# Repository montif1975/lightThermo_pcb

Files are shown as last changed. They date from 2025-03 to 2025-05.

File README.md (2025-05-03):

# lightThermo_pcb
PCB carrier board for lightThermo, based on Raspberry PICO.

Schematic, PCB and construction files (gerber) for PBC carrier for lightThermo but can be used to connect generic I2C add-on on Raspberry PICO.

The project contains two folders:
- lightThermo is the schematic and PCB for single device
- lightThermo_panel is the multi-PCB construction file (2 PCB in a single frame)

The project is made with KiCad 9.0.

The resulting PCB is:
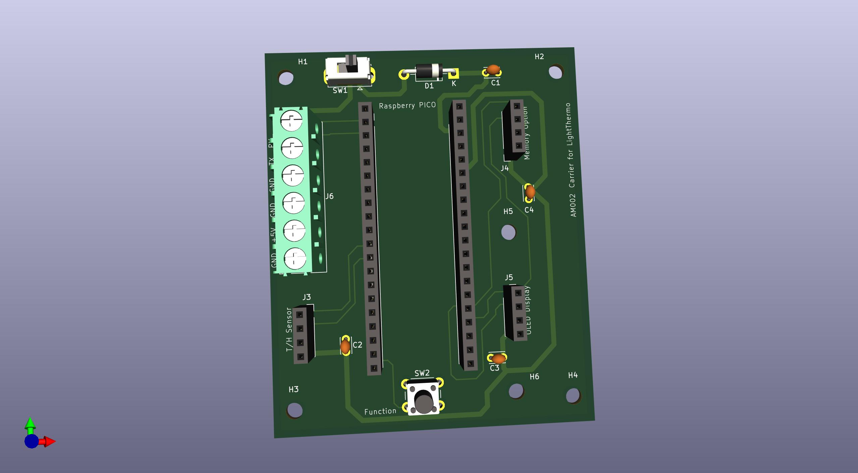
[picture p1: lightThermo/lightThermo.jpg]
lighThermo PCB for carrier board lightThermo


The multi-PCB frame is:
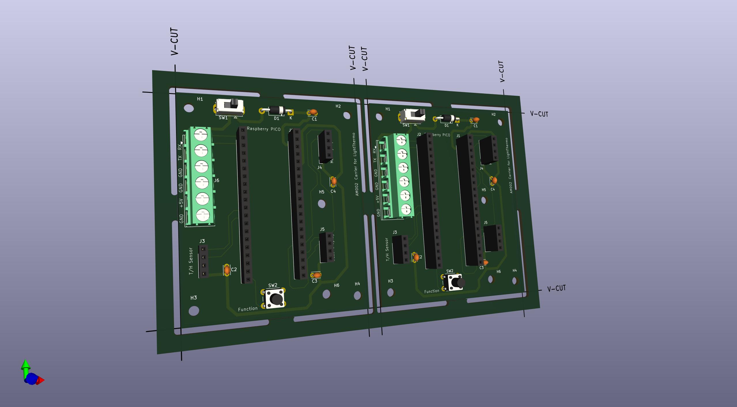
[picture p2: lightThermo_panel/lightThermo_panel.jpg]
lightThermo_panel multi-PCB of carrier board for lightThermo


I printed and assembled some samples, here the PCB (without the PICO and the I2C devices):
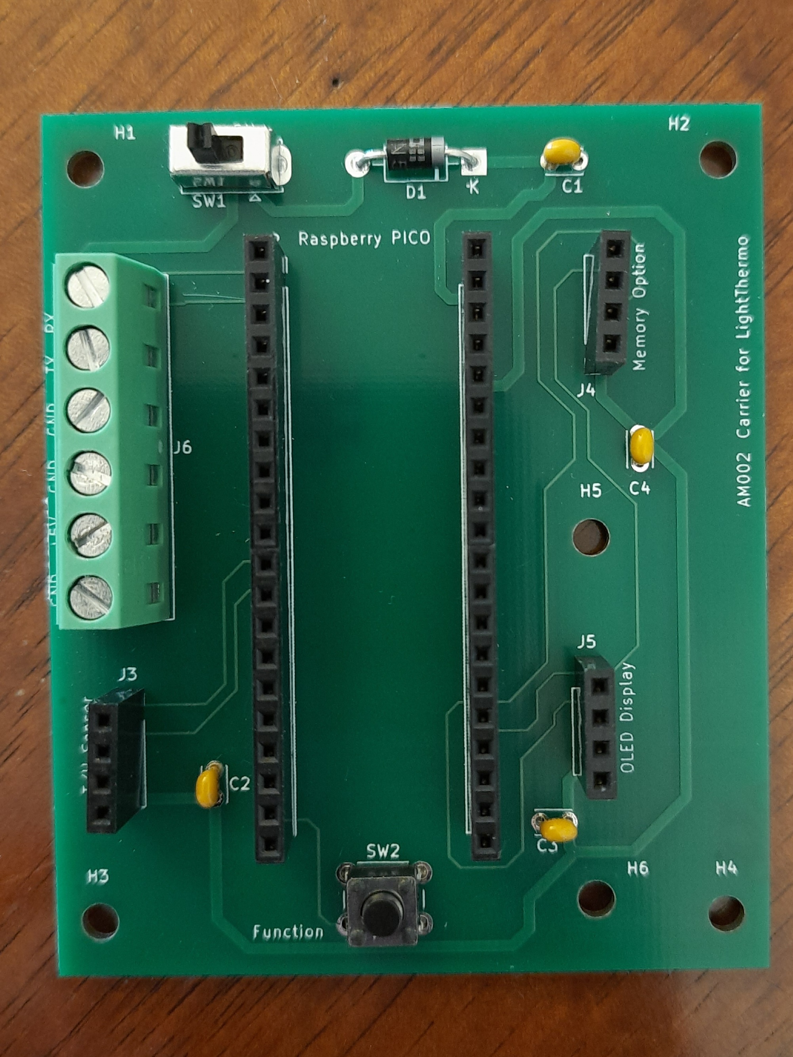
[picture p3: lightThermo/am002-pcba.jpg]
lighThermo PCB for carrier board lightThermo


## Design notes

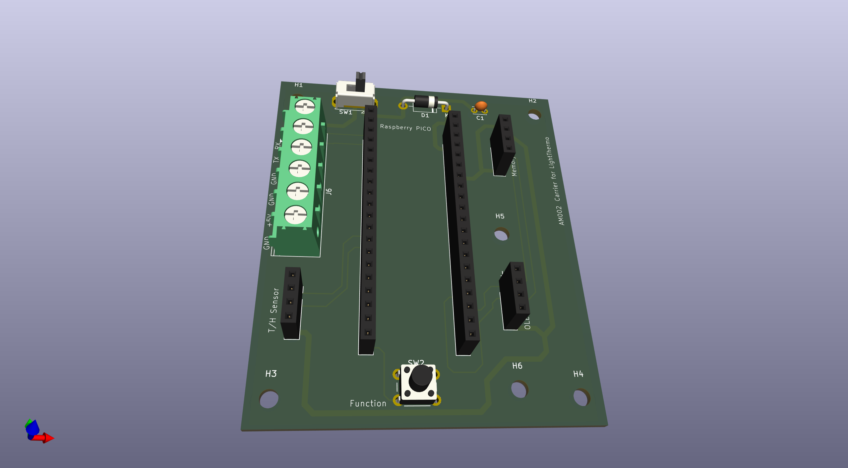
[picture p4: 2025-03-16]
lightThermo/lightThermo.png

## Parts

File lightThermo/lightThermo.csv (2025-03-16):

Reference | Value | Datasheet | Footprint | Qty | DNP
C1,C2,C3,C4 | 100nF | ~ | Capacitor_THT:C_Disc_D3.0mm_W2.0mm_P2.50mm | 4
D1 | 1N5817 | http://www.vishay.com/docs/88525/1n5817.pdf | Diode_THT:D_DO-41_SOD81_P10.16mm_Horizontal | 1
J1 | pico R | ~ | Connector_PinSocket_2.54mm:PinSocket_1x20_P2.54mm_Vertical | 1
J2 | pico L | ~ | Connector_PinSocket_2.54mm:PinSocket_1x20_P2.54mm_Vertical | 1
J3 | Sensor T/H | ~ | Connector_PinSocket_2.54mm:PinSocket_1x04_P2.54mm_Vertical | 1
J4 | Memory Option | ~ | Connector_PinSocket_2.54mm:PinSocket_1x04_P2.54mm_Vertical | 1
J5 | Display OLED | ~ | Connector_PinSocket_2.54mm:PinSocket_1x04_P2.54mm_Vertical | 1
J6 | Screw_Terminal_01x06 | ~ | TerminalBlock_Phoenix:TerminalBlock_Phoenix_PT-1,5-6-5.0-H_1x06_P5.00mm_Horizontal | 1
SW1 | SW_SPST | ~ | Button_Switch_THT:SW_Slide_SPDT_Straight_CK_OS102011MS2Q | 1
SW2 | SW_Push | ~ | Button_Switch_THT:SW_PUSH_6mm_H8mm | 1

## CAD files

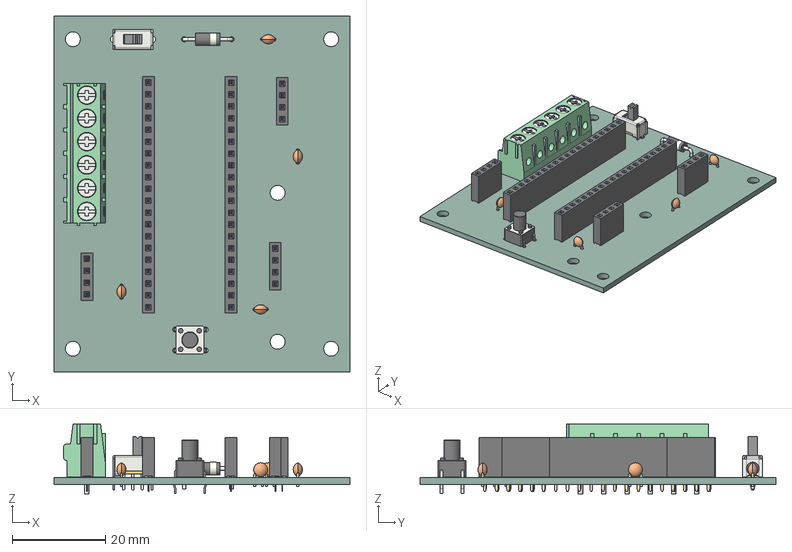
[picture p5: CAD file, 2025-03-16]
lightThermo/lightThermo.step
63.5 x 76.5 x 15.0 mm
C_Disc_D3.0mm_W2.0mm_P2.50mm x 4
D_DO-41_SOD81_P10.16mm_Horizontal
PinSocket_1x04_P2.54mm_Vertical x 3
PinSocket_1x20_P2.54mm_Vertical x 2
SW_Slide_SPDT_Straight_CK_OS102011MS2Q
SW_PUSH_6mm_H8mm
TerminalBlock_Phoenix_PT-1,5-6-5.0-H_1x06_P5.00mm_Horizontal
lightThermo_PCB

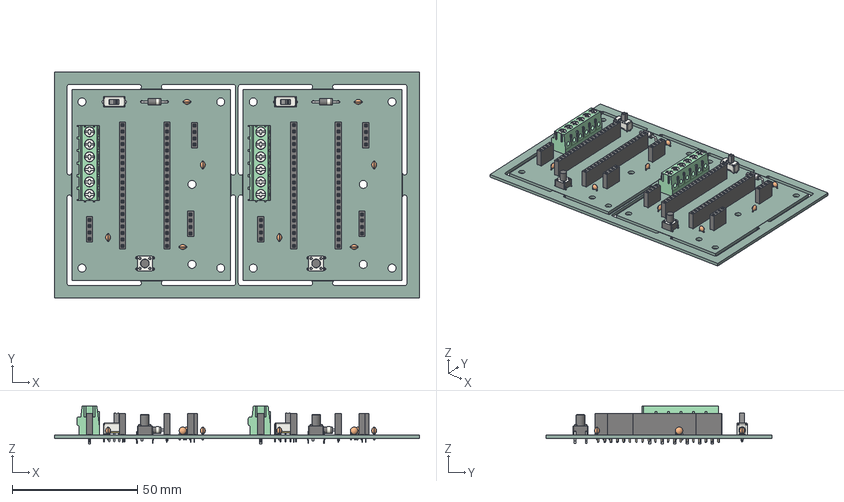
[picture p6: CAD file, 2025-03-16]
lightThermo_panel/lightThermo_panel.step
146.0 x 90.5 x 15.0 mm
PinSocket_1x04_P2.54mm_Vertical x 6
C_Disc_D3.0mm_W2.0mm_P2.50mm x 8
TerminalBlock_Phoenix_PT-1,5-6-5.0-H_1x06_P5.00mm_Horizontal x 2
SW_PUSH_6mm_H8mm x 2
PinSocket_1x20_P2.54mm_Vertical x 4
SW_Slide_SPDT_Straight_CK_OS102011MS2Q x 2
D_DO-41_SOD81_P10.16mm_Horizontal x 2
lightThermo_panel_PCB_1
lightThermo_panel_PCB_2
lightThermo_panel_PCB_3

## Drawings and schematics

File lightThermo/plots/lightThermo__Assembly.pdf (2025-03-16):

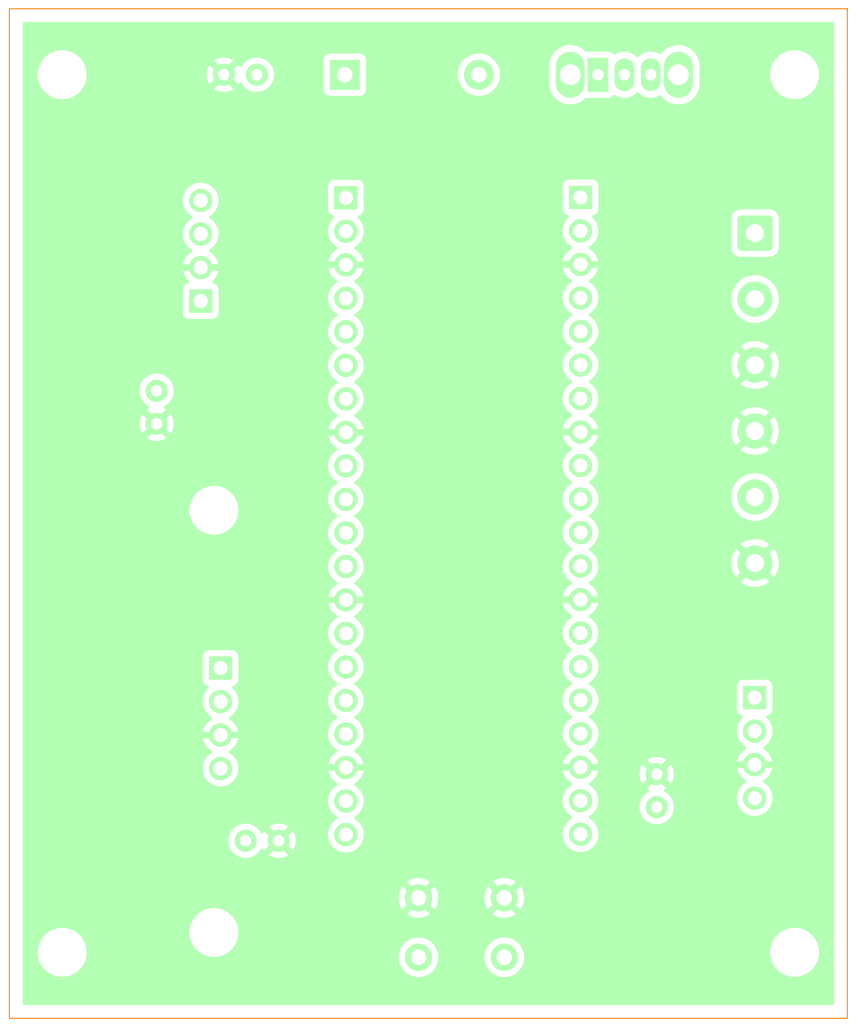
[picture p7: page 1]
D Date: 2025-03-10 KiCad; E.D.A. 9.0.0 Size: A; Rev: 1.0; File: lightThermo.kicad_pcb Sheet: Colored; BOT AM; Board2Pdf:; Colored; BOT -; Page

Id: /1 Title: lightThermo

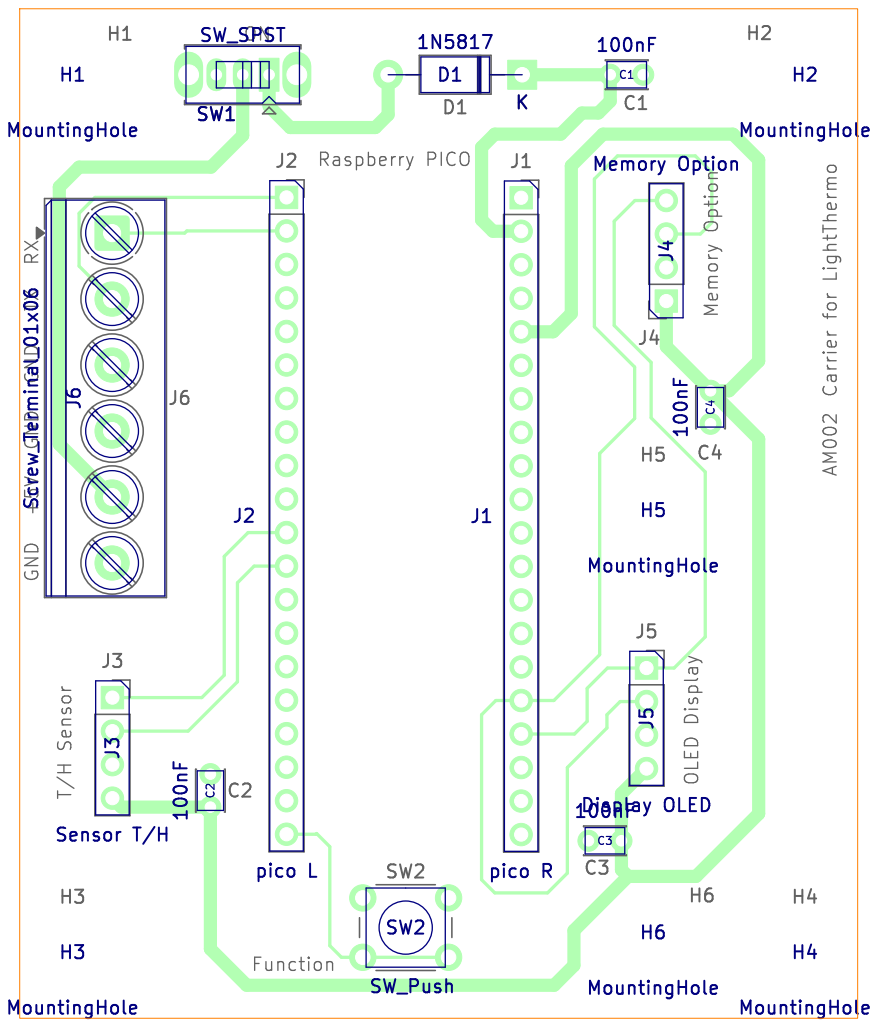
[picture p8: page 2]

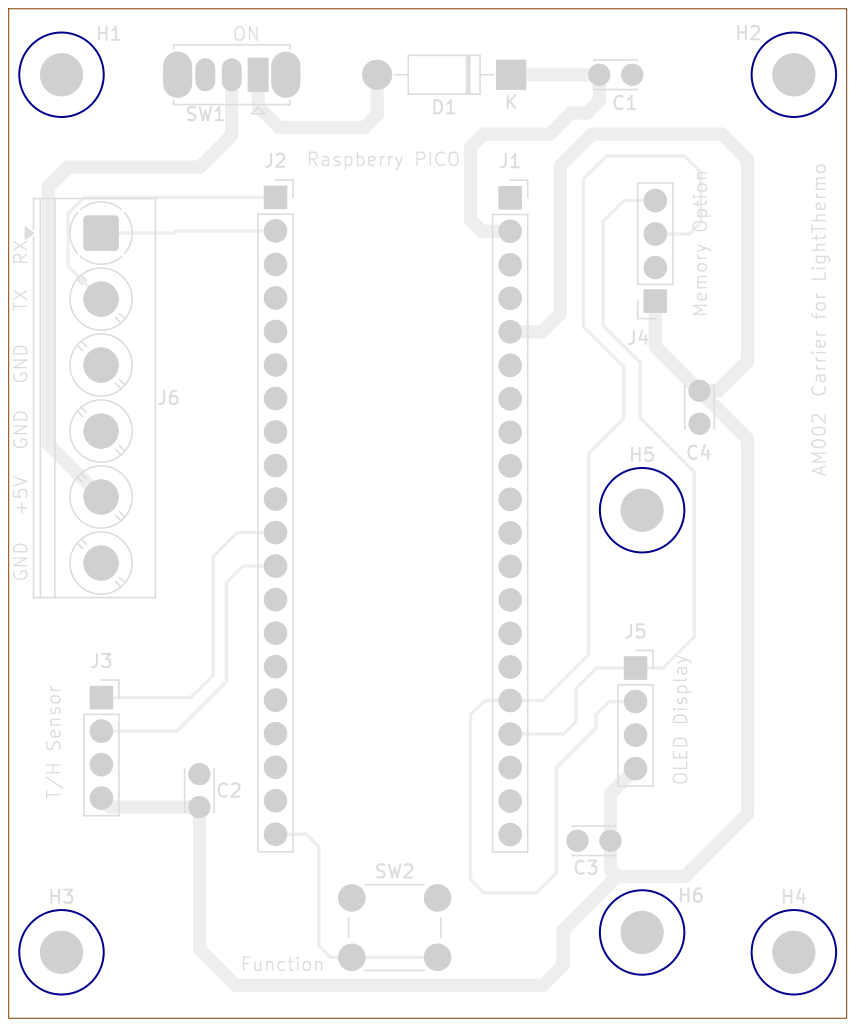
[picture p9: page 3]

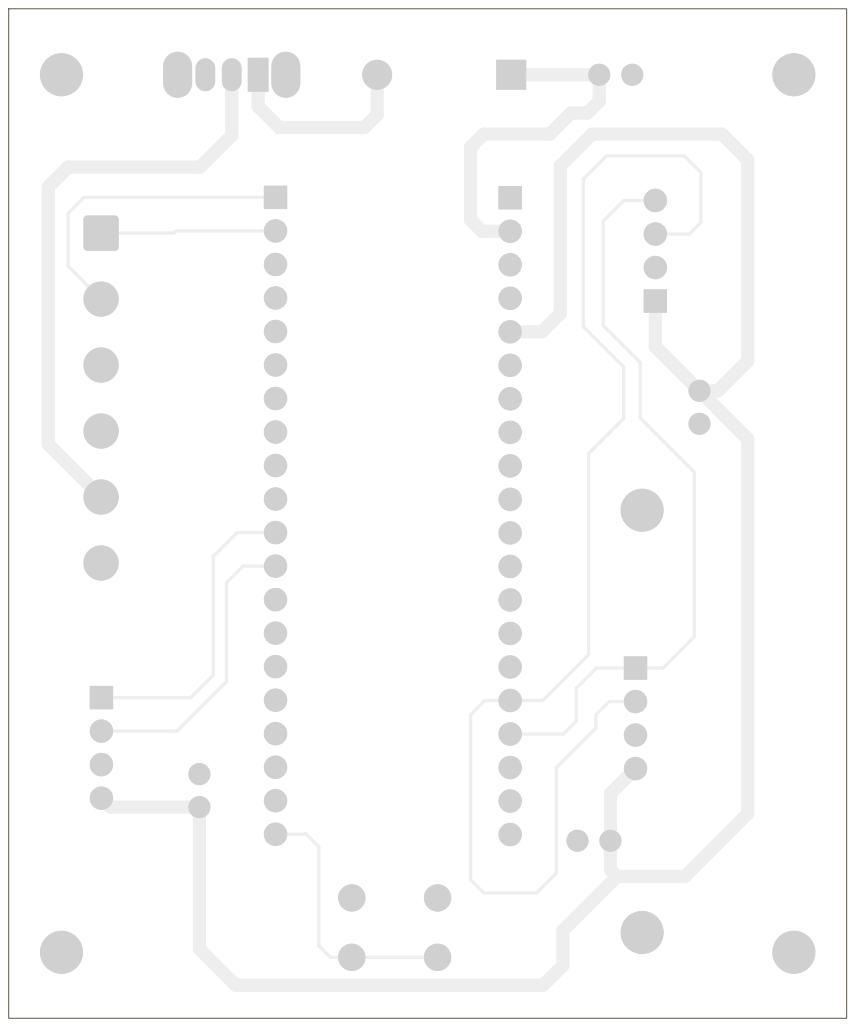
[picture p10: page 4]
D Date: 2025-03-10 KiCad; E.D.A. 9.0.0 Size: A; Rev: 1.0; File: lightThermo.kicad_pcb Sheet: Light Colors; PCB; Paste; TOP AM; Board2Pdf:; Light Colors; TOP -; Page 4/6

Id: /1 Title: lightThermo

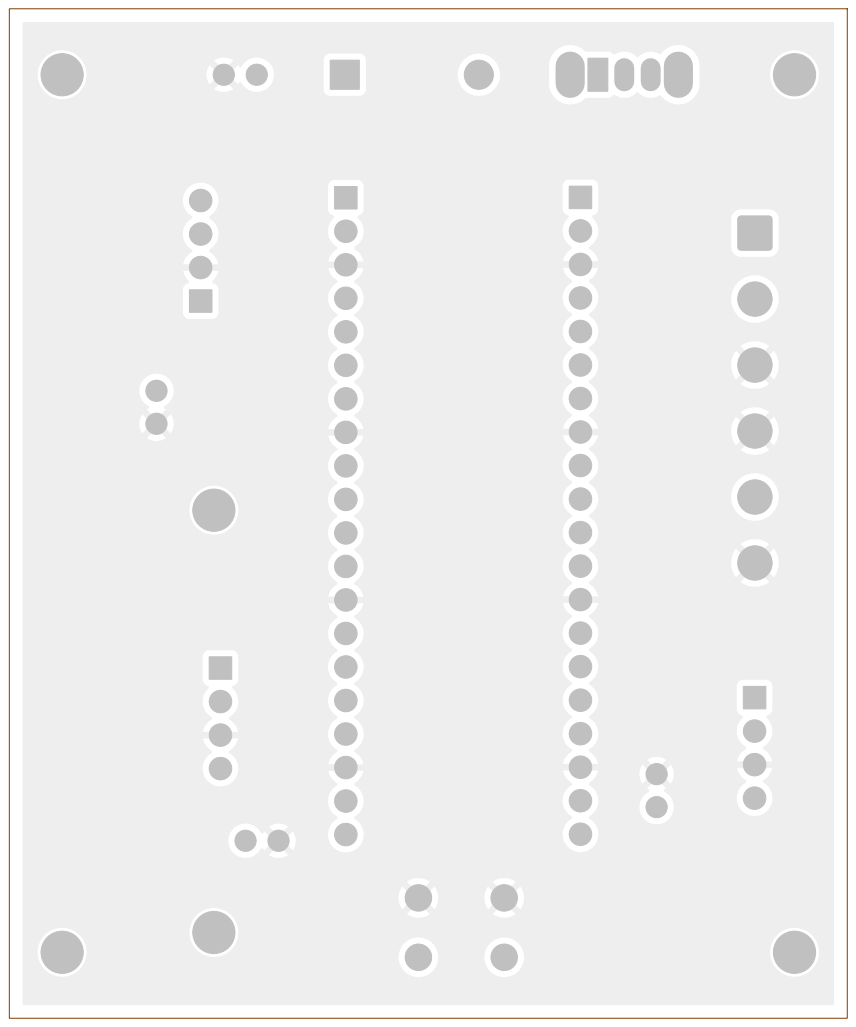
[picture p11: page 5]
D Date: 2025-03-10 KiCad; E.D.A. 9.0.0 Size: A; Rev: 1.0; File: lightThermo.kicad_pcb Sheet: Light Colors; Placement; BOT AM; Board2Pdf:; Light Colors; BOT -; Page 5/6

Id: /1 Title: lightThermo

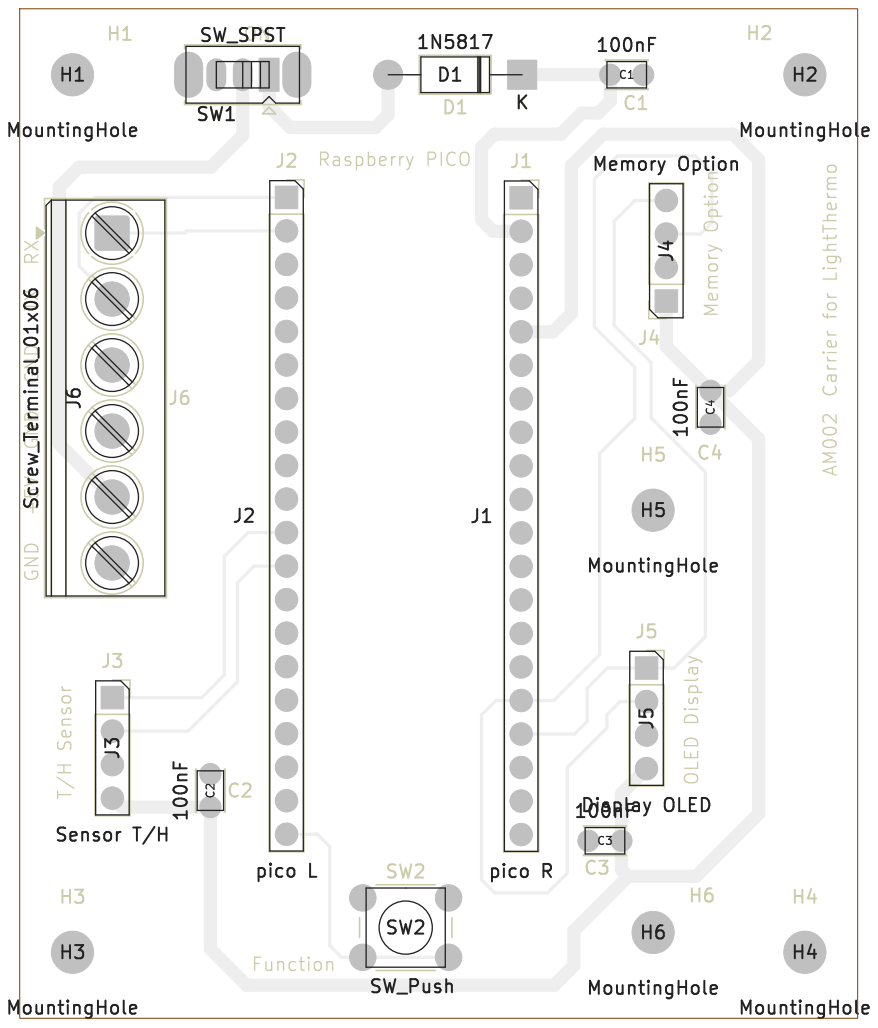
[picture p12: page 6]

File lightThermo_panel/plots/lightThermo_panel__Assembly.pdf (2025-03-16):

1 | 2 | 3 | 4 | 5

A

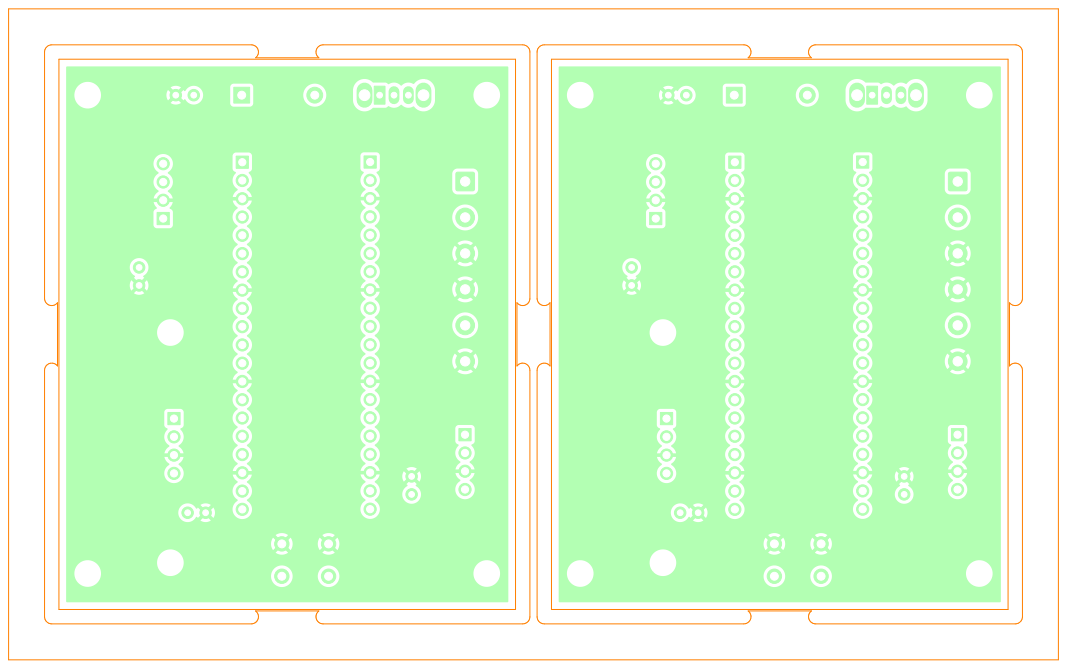
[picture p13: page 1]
D Date: 2025-03-16 KiCad; E.D.A. 9.0.0 Size: A; Rev: 1.1; File: lightThermo_panel.kicad_pcb Sheet: Colored; BOT AM; Board2Pdf:; Colored; BOT -; Page

Id: /1 Title: Carrier board for lightThermo

A

A

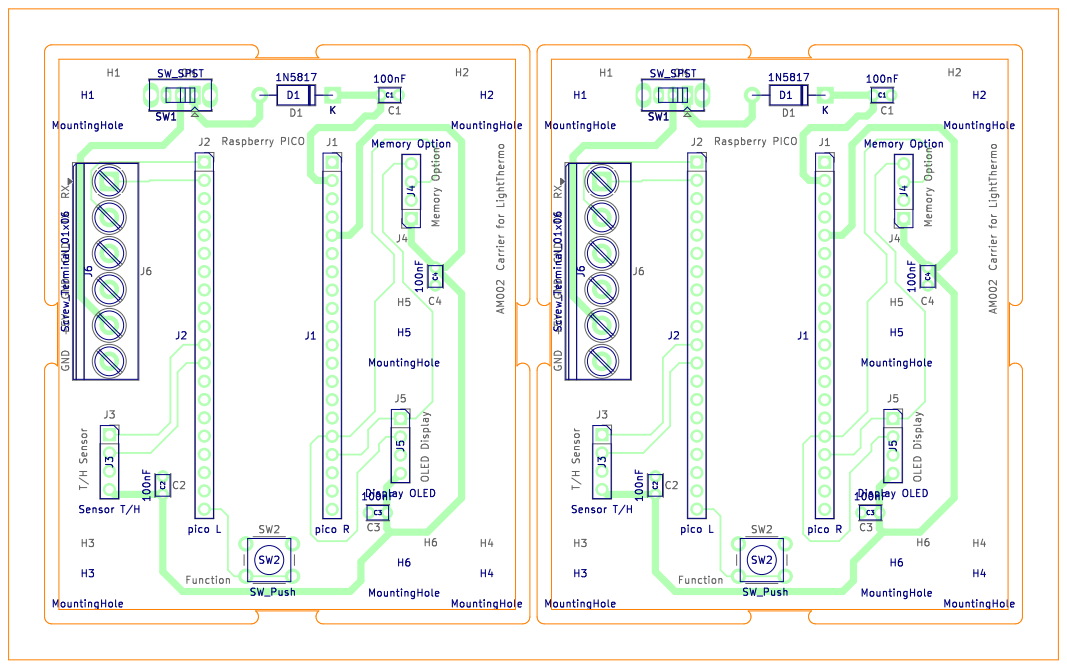
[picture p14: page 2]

Id: /1 Title: Carrier board for lightThermo

A

A

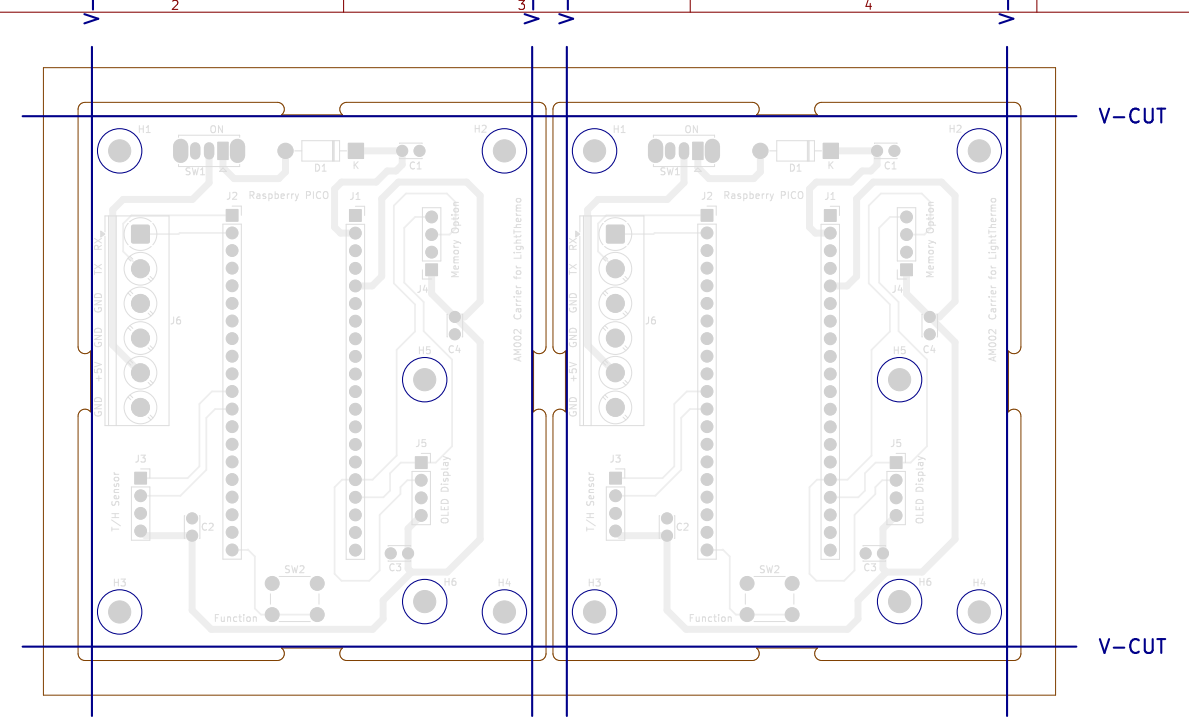
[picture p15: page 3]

Id: /1 Title: Carrier board for lightThermo

A

A

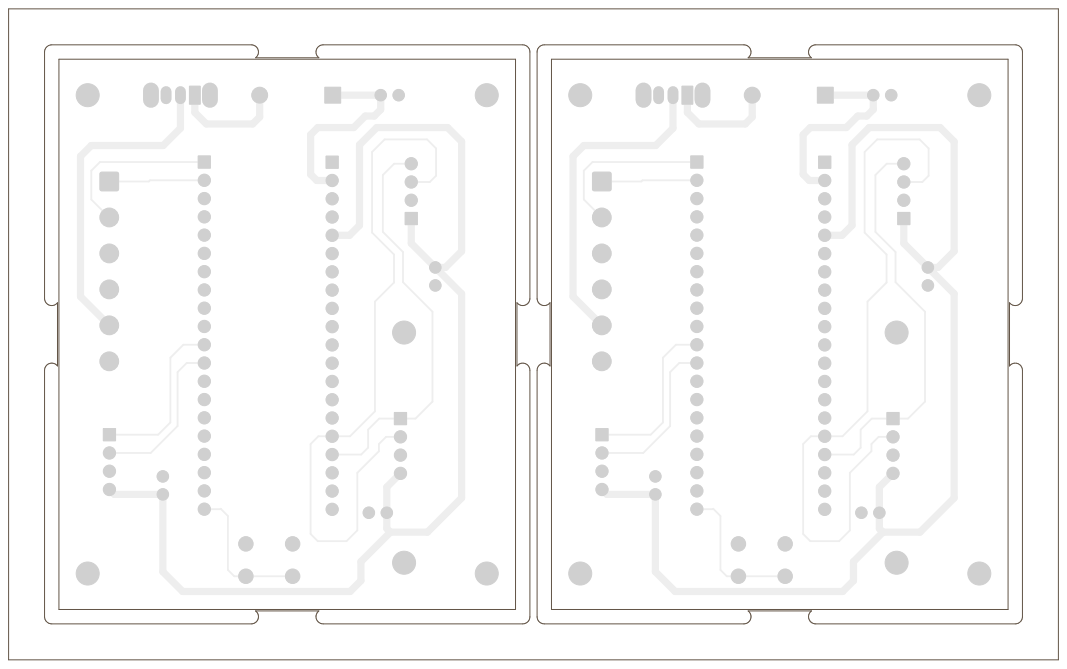
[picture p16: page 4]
D Date: 2025-03-16 KiCad; E.D.A. 9.0.0 Size: A; Rev: 1.1; File: lightThermo_panel.kicad_pcb Sheet: Light Colors; PCB; Paste; TOP AM; Board2Pdf:; Light Colors; TOP -; Page 4/6

Id: /1 Title: Carrier board for lightThermo

A

A

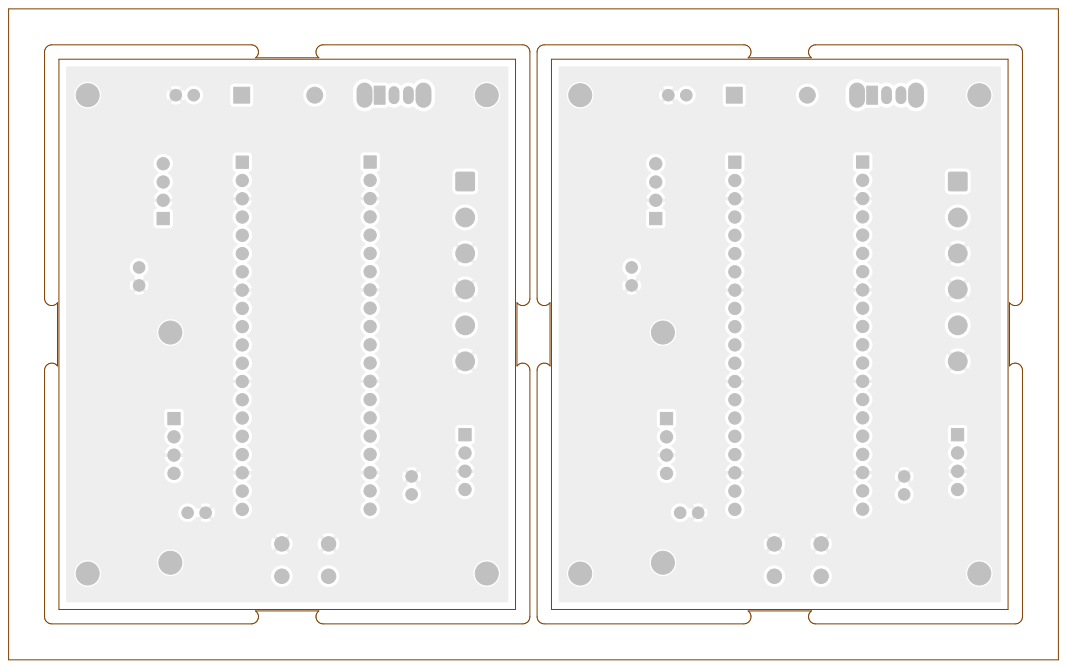
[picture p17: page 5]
D Date: 2025-03-16 KiCad; E.D.A. 9.0.0 Size: A; Rev: 1.1; File: lightThermo_panel.kicad_pcb Sheet: Light Colors; Placement; BOT AM; Board2Pdf:; Light Colors; BOT -; Page 5/6

Id: /1 Title: Carrier board for lightThermo

# C1 pico L

1N5817 D1 | K | Display OLED J5

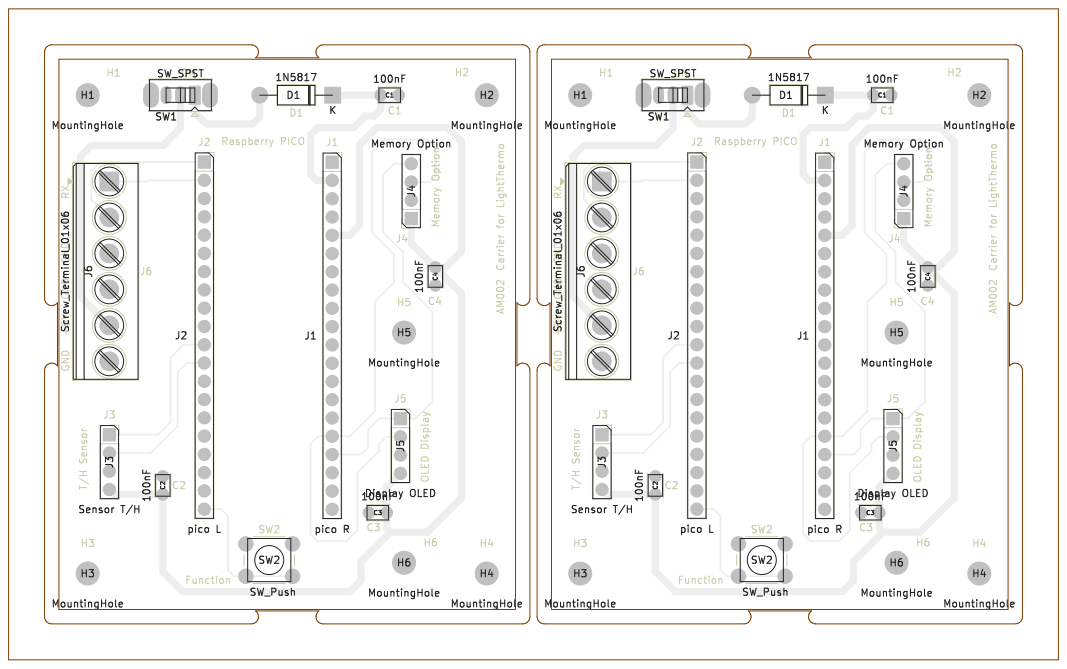
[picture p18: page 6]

Id: /1 Title: Carrier board for lightThermo

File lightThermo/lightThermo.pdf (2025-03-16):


Carrier board for lightThermo
J4 - custom memory option
J5 - Display OLED I2C 128x64 1.3" SH1106

File: lightThermo.kicad_sch Sheet: / AM

Id: 1/1 Title: Carrier board for LightThermo

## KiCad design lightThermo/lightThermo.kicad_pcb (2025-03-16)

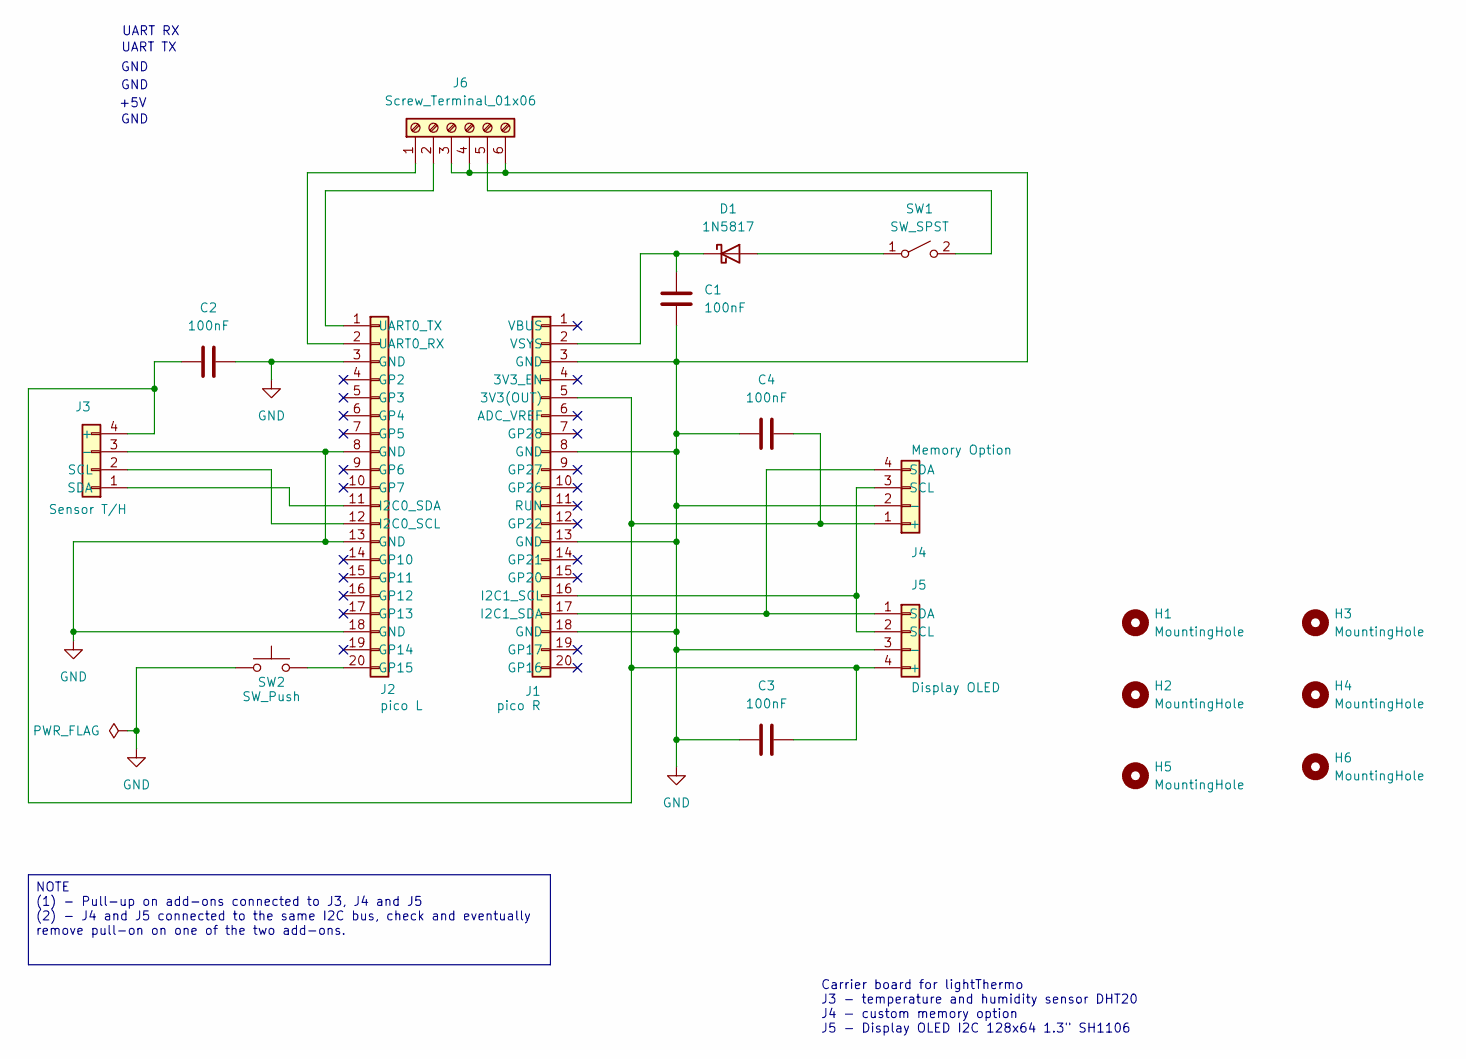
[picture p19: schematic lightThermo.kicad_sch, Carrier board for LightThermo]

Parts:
C1, C2, C3, C4: 100nF; C_Disc_D3.0mm_W2.0mm_P2.50mm
D1: 1N5817; D_DO-41_SOD81_P10.16mm_Horizontal
H1, H2, H3, H4, H5, H6: MountingHole; MountingHole_3.2mm_M3
J1: pico R; PinSocket_1x20_P2.54mm_Vertical
J2: pico L; PinSocket_1x20_P2.54mm_Vertical
J3: Sensor T/H; PinSocket_1x04_P2.54mm_Vertical
J4: Memory Option; PinSocket_1x04_P2.54mm_Vertical
J5: Display OLED; PinSocket_1x04_P2.54mm_Vertical
J6: Screw_Terminal_01x06; TerminalBlock_Phoenix_PT-1,5-6-5.0-H_1x06_P5.00mm_Horizontal
SW1: SW_SPST; SW_Slide_SPDT_Straight_CK_OS102011MS2Q
SW2: SW_Push; SW_PUSH_6mm_H8mm

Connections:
GND: C1.1, C2.1, C3.2, C4.2, J1.3 (GND), J1.8 (GND), J1.13 (GND), J1.18 (GND), J2.3 (GND), J2.8 (GND), J2.13 (GND), J2.18 (GND), J3.3 (-), J4.2 (-), J5.3 (-), J6.3, J6.4, J6.6, SW2.1
unnamed: D1.2 (A), SW1.1 (A)
unnamed: C1.2, D1.1 (K), J1.2 (VSYS)
unnamed: C2.2, C3.1, C4.1, J1.5 (3V3(OUT)), J3.4 (+), J4.1 (+), J5.4 (+)
unnamed: J1.16 (I2C1_SCL), J4.3 (SCL), J5.2 (SCL)
unnamed: J1.17 (I2C1_SDA), J4.4 (SDA), J5.1 (SDA)
unnamed: J2.20 (GP15), SW2.2
unnamed: J2.12 (I2C0_SCL), J3.2 (SCL)
unnamed: J2.11 (I2C0_SDA), J3.1 (SDA)
unnamed: J2.2 (UART0_RX), J6.1
unnamed: J2.1 (UART0_TX), J6.2
unnamed: J6.5, SW1.2 (B)

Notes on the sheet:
GND
UART RX
Carrier board for lightThermo J3 - temperature and humidity sensor DHT20 J4 - custom memory option J5 - Display OLED I2C 128x64 1.3" SH1106
UART TX
+5V
NOTE (1) - Pull-up on add-ons connected to J3, J4 and J5 (2) - J4 and J5 connected to the same I2C bus, check and eventually remove pull-on on one of the two add-ons.

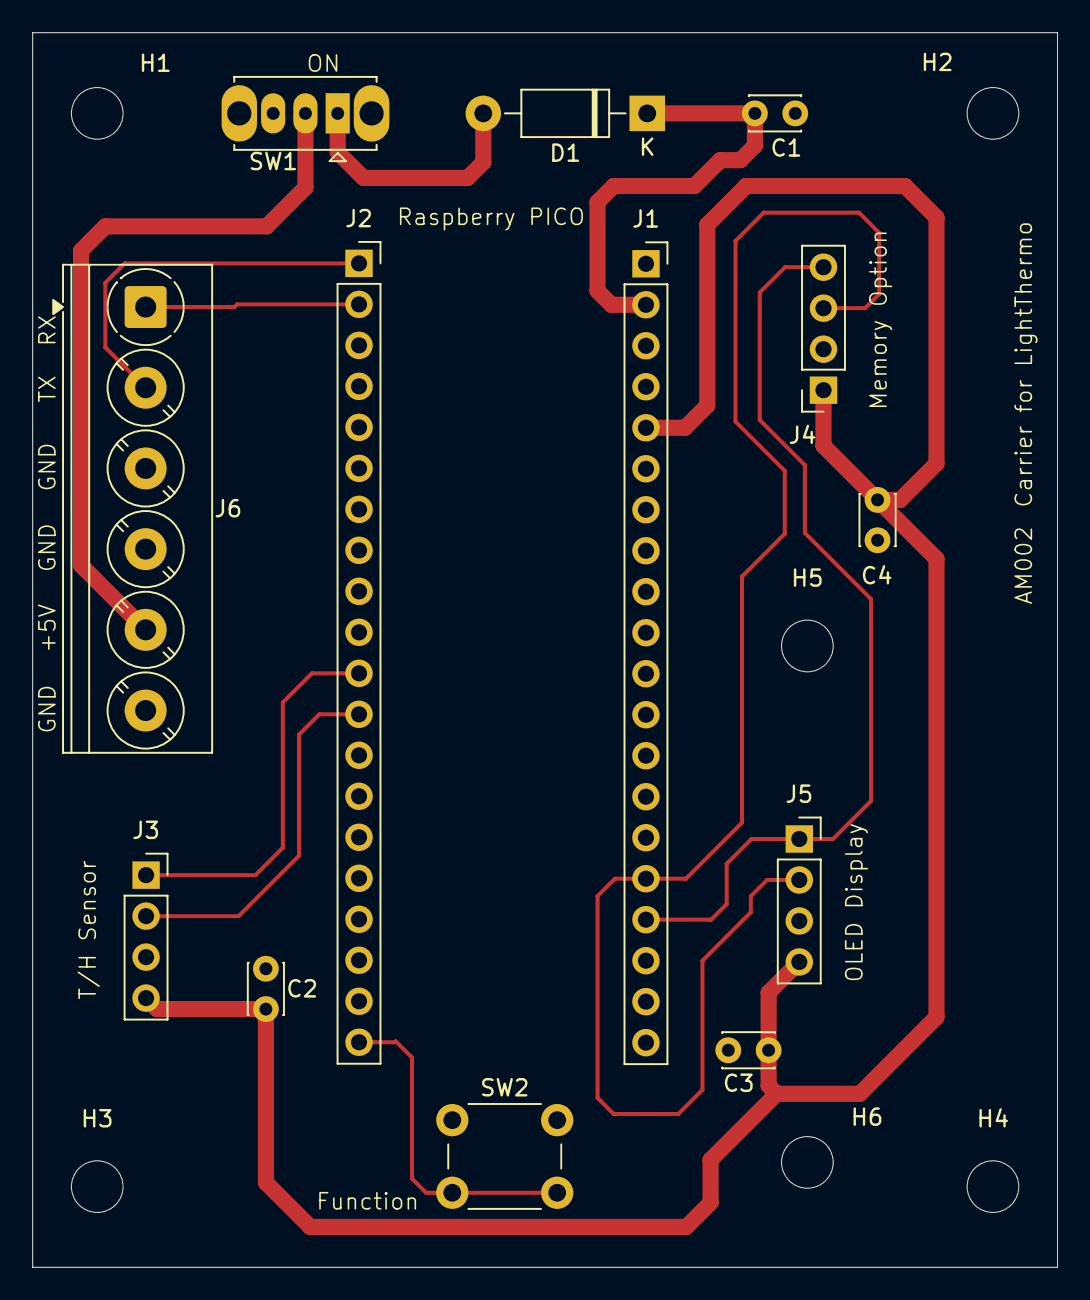
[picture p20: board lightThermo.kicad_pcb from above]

Board: 2 copper layers, 63.5 x 76.5 mm, 19 parts (0 on the bottom side), 12 nets.

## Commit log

2025-03-16 Add files via upload
    First commit
    [lightThermo.csv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]
2025-05-03 Updated README and add a picture of the PCB assembled.
